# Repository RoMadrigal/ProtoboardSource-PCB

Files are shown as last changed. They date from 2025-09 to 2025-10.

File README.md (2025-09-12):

# ProtoboardSource-PCB
Repositorio del diseño de una PCB que permite conectar directamente cables con conector banana para alimentar una protoboard

Este repositorio y sus contenidos fueron diseñados por:

<div align="center">

| **Nombre** | **Correo electrónico**|
|:---:|:---:|
| Rodrigo Madrigal Montes |  rmadrigalmontes@gmail.com |

</div>

## Agradecimientos a PCBWay

Quiero expresar mi agradecimiento a **PCBWay** por su colaboración y apoyo en la fabricación de esta PCB. La calidad de las placas recibidas, tanto en precisión de fabricación como en acabados, encajaron perfectamente con las dimensiones y especificaciones con las que las diseñé. Esto siempre es vital y más aún en una PCB de este tipo que debe encajar en una *Protoboard* con dimensiones muy específicas. 

### PCB ensamblada

Una vez recibidas las placas de **PCBWay**, se procedió con el ensamblaje manual de todos los componentes. A continuación se muestran imágenes del resultado final:

<div align="center">

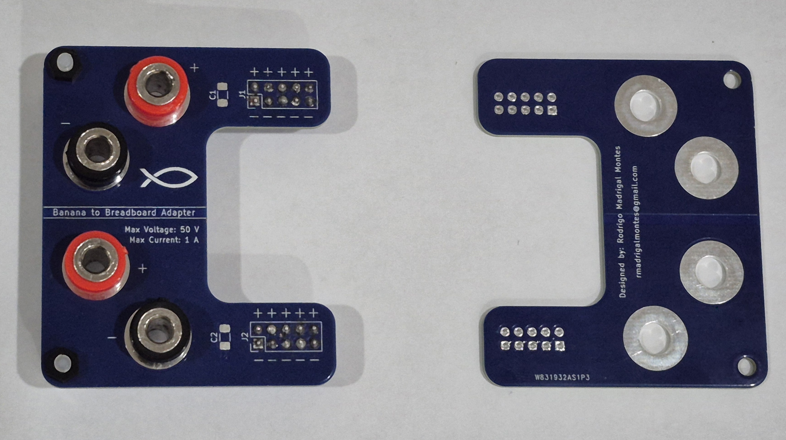
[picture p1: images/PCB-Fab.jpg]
PCB ensamblada - no montada en la Protoboard
|  |
|:--:|
| *PCB ensamblada - no montada en la Protoboard* |

</div>

<div align="center">

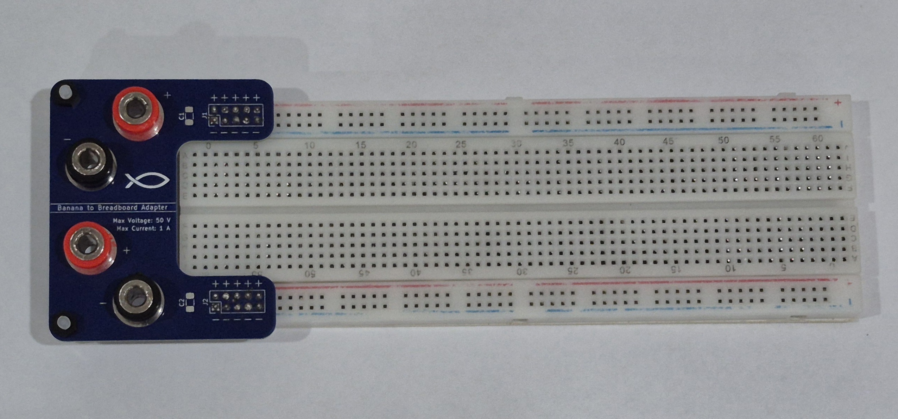
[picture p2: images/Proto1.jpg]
PCB ensamblada - montada en la Protoboard
|  |
|:--:|
| *PCB ensamblada - montada en la Protoboard* |

</div>

### Demostración de funcionamiento

A continuación, se presentan imágenes mostrando la PCB montada en una *Protoboard* y conectada a una fuente de tensión de laboratorio, y midiendo la tensión que suministra con un multímetro:

<div align="center">

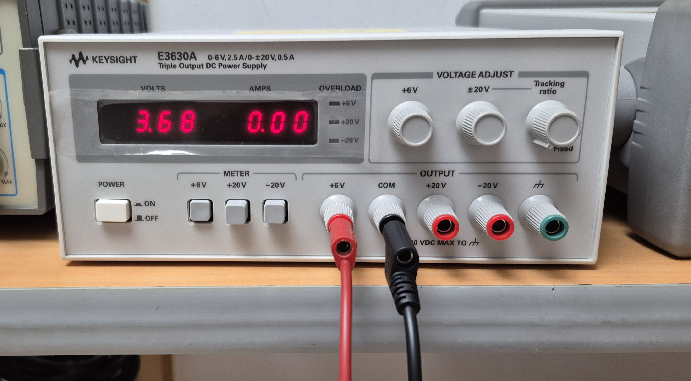
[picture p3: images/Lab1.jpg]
Fuente de laboratorio ajustada en 3.68 V
|  |
|:--:|
| *Fuente de laboratorio ajustada en 3.68 V* |

</div>

<div align="center">

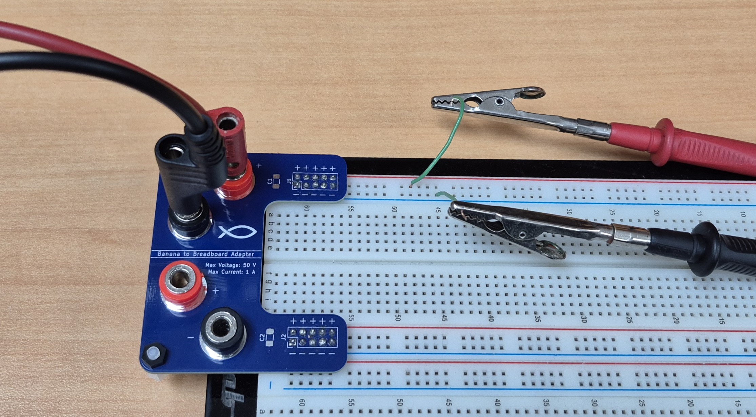
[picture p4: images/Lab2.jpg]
PCB conectada a la fuente y montada en la Protoboard
|  |
|:--:|
| *PCB conectada a la fuente y montada en la Protoboard* |

</div>

<div align="center">

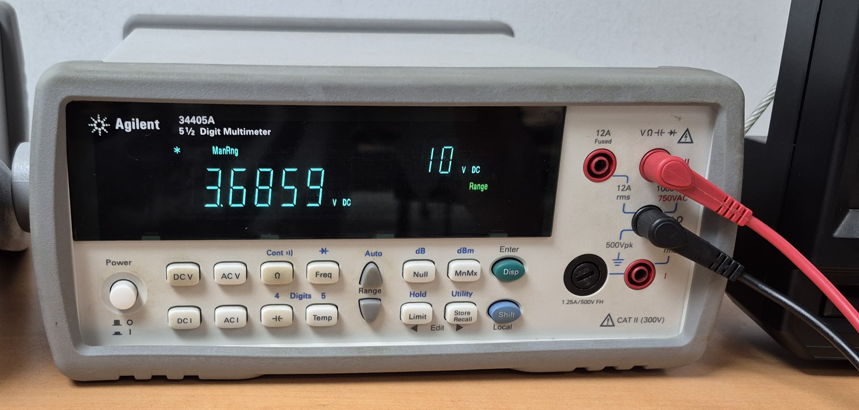
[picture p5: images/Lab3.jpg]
Medida de tensión suministrada a la Protoboard
|  |
|:--:|
| *Medida de tensión suministrada a la Protoboard* |

</div>

Gracias a su servicio confiable y de altísima calidad, logré ensamblar y probar con éxito esta PCB, cumpliendo el objetivo del diseño. Recomiendo sus servicios para estudiantes, profesionales y cualquier persona interesada en manufacturar PCBs de alta calidad. Más información en [pcbway.com](https://www.pcbway.com).

## Organización y contenido de los directorios 

Este repositorio contiene dos directorios principales, cuyos contenidos son:

- `kicad_project`: Contiene los archivos de diseño y configuarción del proyecto
    - `CargadorWalkieTalkie.kicad_pcb`
    - `CargadorWalkieTalkie.kicad_pro`
    - `CargadorWalkieTalkie.kicad_sch`

- `outputs`: Contiene todos los archivos de salida de *KiCad*

Si se desea utilizar este diseño y manufacturarlo por medio de un fabricante se debe comprimir los archivos incluidos en la carpeta `outputs` en un archivo `.zip` y este se puede cargar en la página del fabricante para ordenar la fabricación de la PCB. 

## Diseño del esquemático

El propósito del circuito es poder alimentar de forma segura y firme una *protoboard* o *breadboard* con cables banana provenientes de fuentes profesionales de laboratorio, para evitar conexiones flojas, peligrosas e ineficientes; como por ejemplo enrollar un cable alrededor del conector banana e introducirlo luego en la *protoboard*. 

Para solucionar este problema se propone el circuito representado en el siguiente esquemático:

<div align="center">

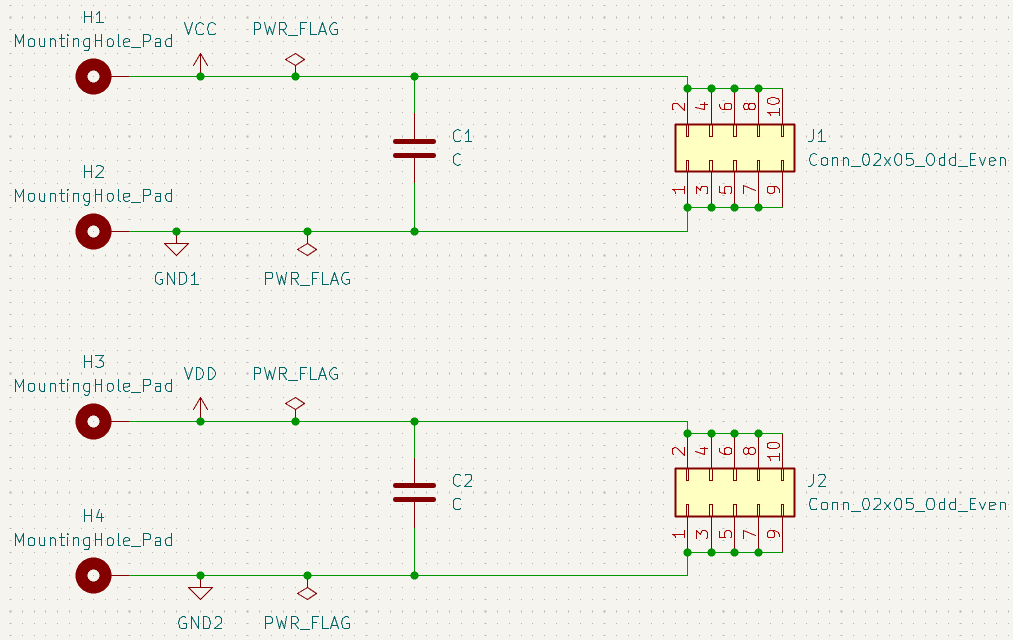
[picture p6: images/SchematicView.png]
Diseño del esquemático*
|  |
|:--:|
| *Diseño del esquemático* |

</div>

Como se observa se cuenta con dos circuitos de alimentación idénticos por separado, uno para cada pista de alimentación de la protoboard. Además en cada circuito se encuentra un capacitor que tiene la función de filtrar ruido proveniente de la fuente de alimentación que se esté utilizando. 

Otra observación importante es el hecho de que los conectores que entran en lo pines de la *protoboard* están conectados en paralelo, se tomó la decisión de usar cinco pares de pines entre el positivo y negativo de la fuente en lugar de un solo par de pines para dar mayor estabilidad al momento de conectarse en la *protoboard*. Pero si se desea usar menos pines al estar todos en paralelo no habría ningún problema si se decide hacerlo de esta manera. 

## Lista de componentes

A continuación se incluye una lista con los componentes utilizados en el diseño, con el mismo número que se les asignó en el diseño final de PCB:

<div align="center">

| Componente | Valor / Modelo | Descripción |
|:---:|:---:|:---:|
| C1 / C2 | 10 µF a 50 V | Capacitor cerámico SMD 1206 |
| Pines para conectar a la Protoboard | Pin Headers de 2.54mm de separación y 11.5mm de longitud | Pin Headers |
|Conectores Banana para alimentación | Conector Banana Hembra para chasis | Conector Banana Hembra |
| Postes de nylon | Postes y tuercas de nylon M3 | Postes y tuercas de nylon |

</div>

## Diseño de la PCB

Una vez definido el circuito final, se diseñó la PCB en *KiCad* con una arquitectura de **dos capas**:

- **F.Cu**: Plano de alimentación (VCC y VDD)
- **B.Cu**: Plano de tierra (GND1 y GND2)

### Capas de la PCB

<div align="center">

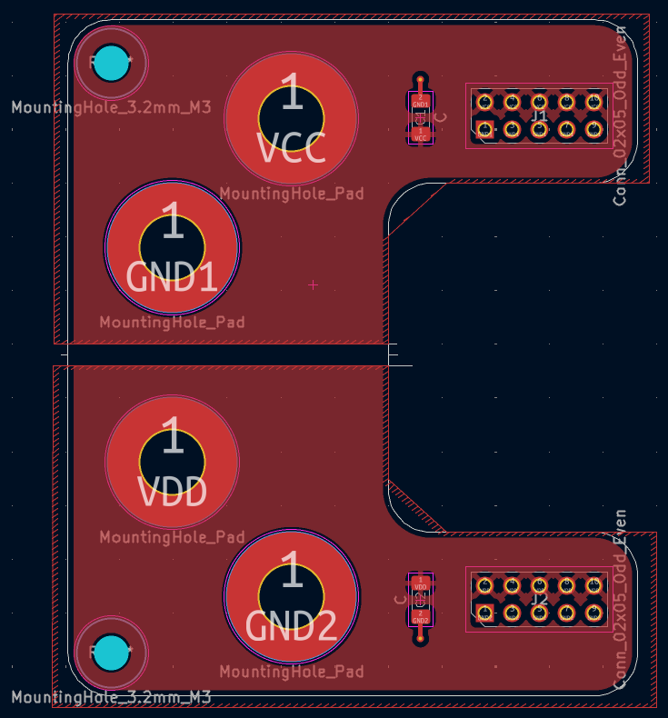
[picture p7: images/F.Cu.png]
Capa F.Cu
|  |
|:-----------------------------:|
|    *Capa superior (F.Cu)*     |

</div>

<div align="center">

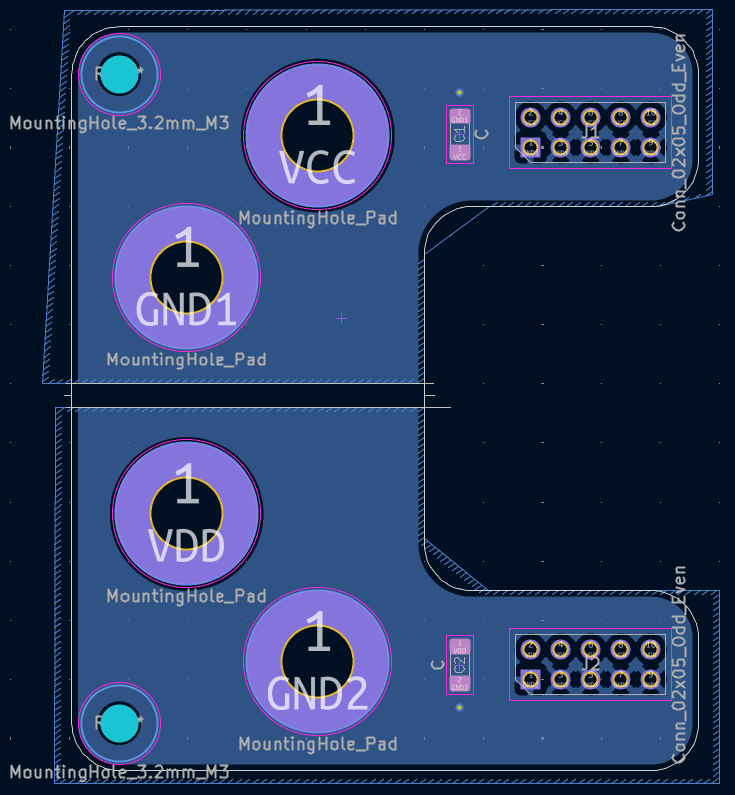
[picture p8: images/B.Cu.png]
Capa B.Cu
|  |
|:-----------------------------:|
|    *Capa inferior (B.Cu)*     |

</div>

> [!NOTE]
> Se observa como los planos de alimentación positiva (VCC, VDD) y alimentación negativa (GND1, GND2) están separados por un espaciado físico en la parte central de la PCB para evitar cualquier tipo de interferencia o fuga de corriente entre ambos rieles de alimentación al conectarlo en la *Protoboard*.

Además, se agregaron zonas de serigrafía, agujeros de montaje, así como textos identificativos y un logotipo en el *silkscreen*, además del nombre del proyecto y los datos del autor. Finalmente se muestran resultados de la vista 3D de la PCB en KiCad. 

<div align="center">

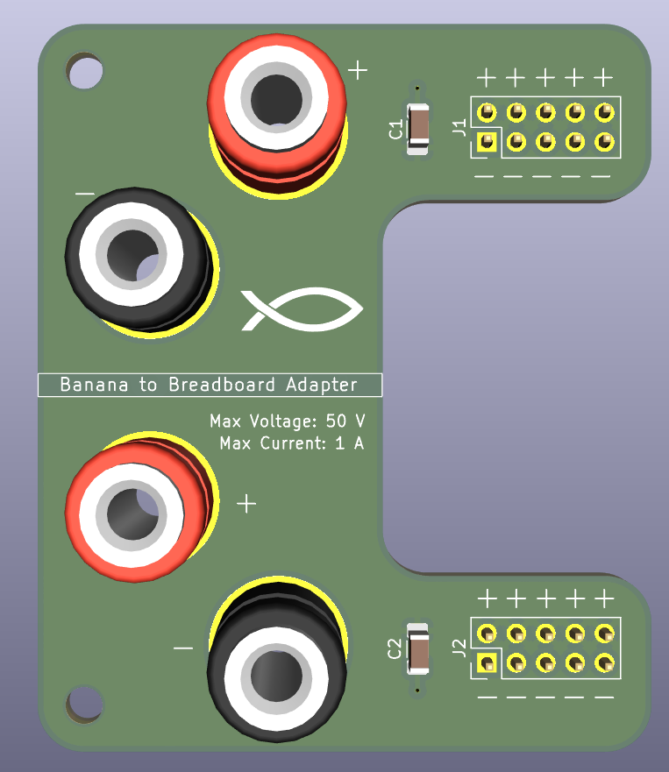
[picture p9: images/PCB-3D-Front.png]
Vista 3D Frontal de la PCB
|  |
|:--:|
| *Vista 3D Frontal de la PCB en KiCad* |

</div>

<div align="center">

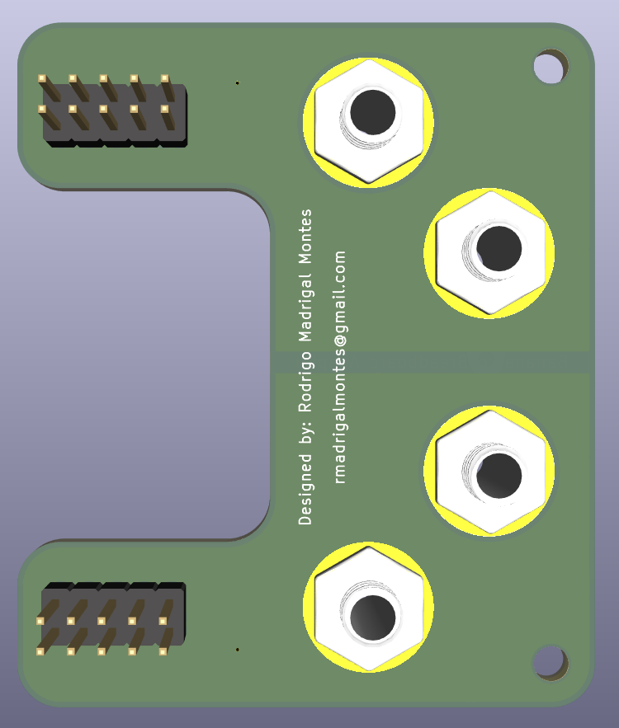
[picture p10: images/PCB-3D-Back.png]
Vista 3D Trasera de la PCB
|  |
|:--:|
| *Vista 3D Trasera de la PCB en KiCad* |

</div>

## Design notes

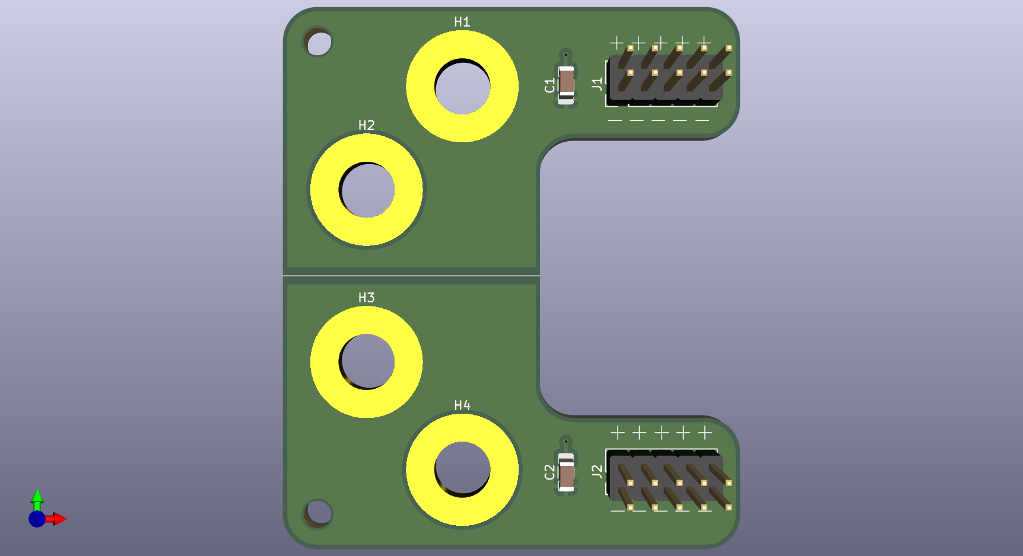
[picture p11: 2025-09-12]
images/PCB-Fill.png

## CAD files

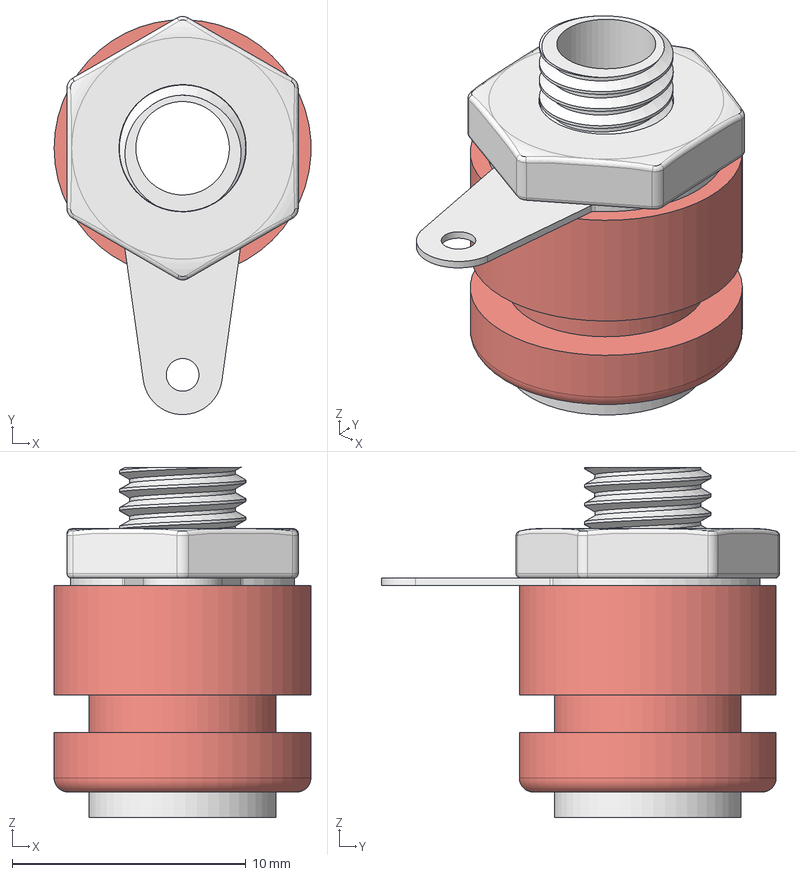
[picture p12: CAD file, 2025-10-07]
kicad_project/3Dmodels/4mm Red Banana Female Socket Jack Mount Connectors.step
11.0 x 17.0 x 15.0 mm

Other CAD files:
kicad_project/3Dmodels/4mm Black Banana Female Socket Jack Mount Connectors.step

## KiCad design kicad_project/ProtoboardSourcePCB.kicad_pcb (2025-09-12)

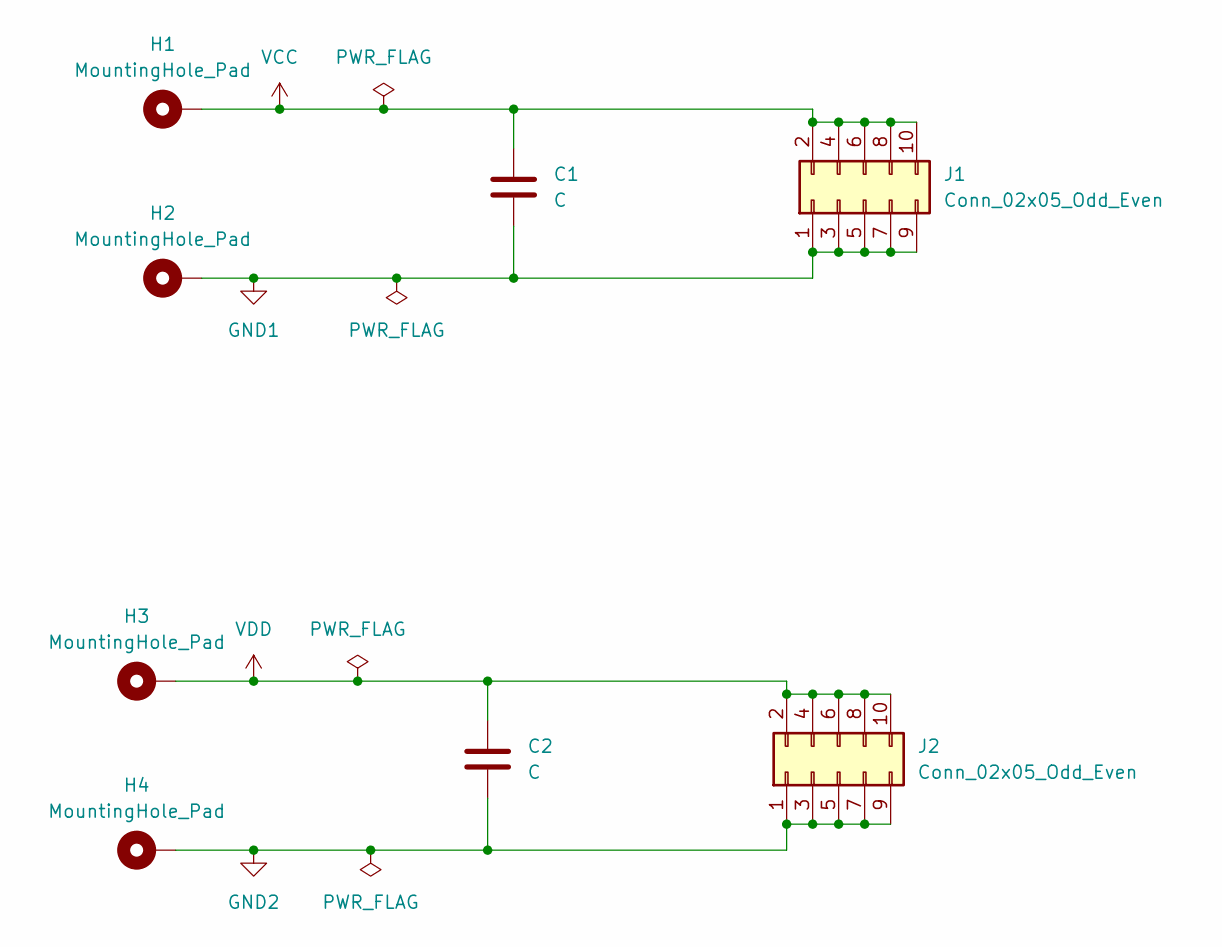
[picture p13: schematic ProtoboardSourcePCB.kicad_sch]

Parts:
C1, C2: C; C_1206_3216Metric_Pad1.33x1.80mm_HandSolder
H1, H2, H3, H4: MountingHole_Pad; MountingHole_6mm_Pad
J1, J2: Conn_02x05_Odd_Even; PinHeader_2x05_P2.54mm_Vertical

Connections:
GND1: C1.2, H2.1, J1.1, J1.3, J1.5, J1.7, J1.9
GND2: C2.2, H4.1, J2.1, J2.3, J2.5, J2.7, J2.9
VCC: C1.1, H1.1, J1.2, J1.4, J1.6, J1.8, J1.10
VDD: C2.1, H3.1, J2.2, J2.4, J2.6, J2.8, J2.10

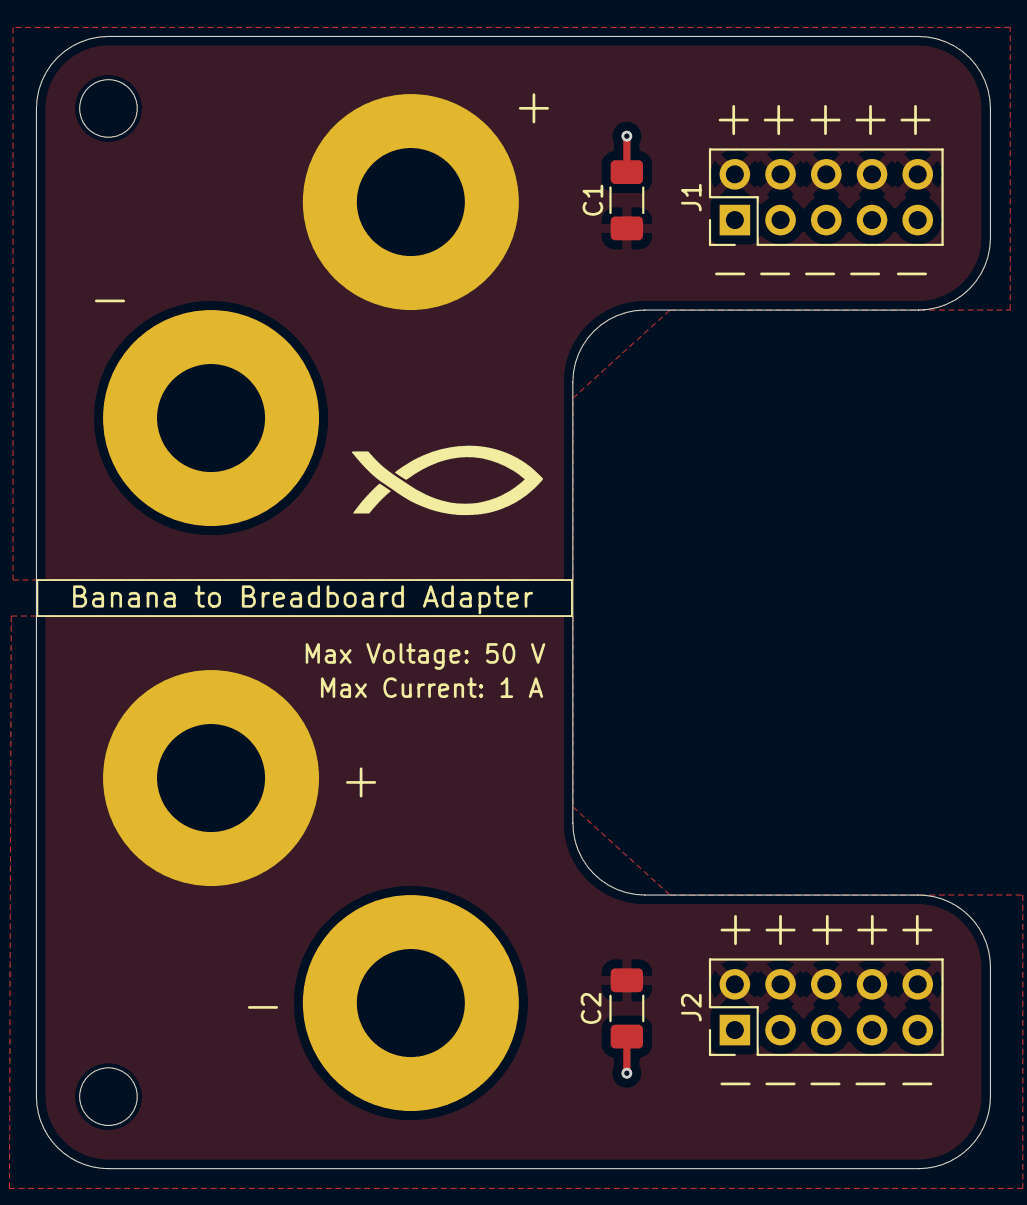
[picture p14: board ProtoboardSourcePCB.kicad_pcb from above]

Board: 2 copper layers, 53.0 x 62.9 mm, 8 parts (0 on the bottom side), 4 nets.

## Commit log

2025-07-23 Agregando archivos del proyecto de KiCad
    [ProtoboardSourcePCB.kicad_pcb, ProtoboardSourcePCB.kicad_sch]
2025-07-23 Agregando nombre del autor en el README.md
2025-07-24 Corrigiendo huellas, colocando componentes y delimitando espacio de la PCB
    [ProtoboardSourcePCB.kicad_pcb, ProtoboardSourcePCB.kicad_sch]
2025-07-27 Modificando huella de los capacitores y reacomodando componentes
    [ProtoboardSourcePCB.kicad_pcb, ProtoboardSourcePCB.kicad_sch]
2025-07-27 Modificando dimensiones de la PCB y agregando texto en Silkscreen
    [ProtoboardSourcePCB.kicad_pcb]
2025-07-29 Agregando agujeros de montaje en la PCB
    [ProtoboardSourcePCB.kicad_pcb]
2025-07-29 Definiendo los planos de tierra y alimentacion, y agregando vias para los capacitores
    [ProtoboardSourcePCB.kicad_pcb]
2025-08-07 Modificando huellas de conector banana y reacomodando huella de C2
    [ProtoboardSourcePCB.kicad_pcb, ProtoboardSourcePCB.kicad_sch]
2025-08-08 Se agregan imagenes en la carpeta images y se agregan secciones en el README.md
2025-08-08 Agregando especificaciones y nombres en la Silkscreen de la PCB
    [ProtoboardSourcePCB.kicad_pcb]
2025-08-15 Agregando ultimos detalles y logo en el Silkscreen
    [ProtoboardSourcePCB.kicad_pcb]
2025-09-12 Agregando archivos de fabricacion en el directorio outputs
    [ProtoboardSourcePCB-B_Cu.gbl, ProtoboardSourcePCB-B_Mask.gbs, ProtoboardSourcePCB-B_Paste.gbp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]
2025-09-12 Se agregan logo y ultima reubicacion de componentes en la PCB
    [ProtoboardSourcePCB.kicad_pcb]
2025-09-12 Agregando demostracion de funcionamiento y agradecimentos a PCBWay en el README.md
2025-10-07 Agregando directorio de modelos 3D en la carpeta del proyecto
    [4mm Black Banana Female Socket Jack Mount Connectors.step, 4mm Red Banana Female Socket Jack Mount Connectors.step]
2025-10-07 Modificando imagenes de vista 3D con modelos 3D agregados en el README.md
